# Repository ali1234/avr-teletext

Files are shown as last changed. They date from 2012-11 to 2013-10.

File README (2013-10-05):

avr-teletext
------------

This is a teletext inserter for AVR microcontroller. It adds teletext to an
existing composite signal. It is controlled on I2C and features two modes.
In passthrough mode whole teletext packets are received on I2C and inserted
into the video signal, allowing the broadcast of an interleaved magazine with
multiple pages. In console mode the I2C port receives individual characters
and emulates a framebuffer by generating a single page repeatedly. The console
supports accelerated scrolling.

A video of the device operating is here:
https://plus.google.com/117474986382867317779/posts/eKBn5ePYWbc

Hardware
--------

The hardware schematic is in schematic.png. General parts list:

 * AVR microcontroller. I used Atmega 168. Using a part with more RAM would
   allow for multiple consoles are other fancy stuff.

 * LM1881 sync splitter. For generating horizontal and vertical sync pulses.
   Hard to find in through hole package. I got it at http://www.rapidonline.com

 * 13.875 MHz crystal. For AVR clock. This is double teletext frequency.
   Extremely hard to find. I got it from http://quarndon.co.uk/

 * A diode to hook up the teletext to the video signal.

 * Various resistors and capacitors. Especially you need some filter caps 
   between ground and vcc or the output signal will be too dirty to work.

I2C addresses
-------------

The AVR implements two I2C addresses: data and control.

0x00 - Data address

Bits    Function
0-6     7 bit characters written here will be placed into the output buffer.
7       Unused.

0x01 - Control address

Bits
0       Set mode. 0 = console, 1 = passthrough.
1-7     Unused.

Console mode
------------

In this mode each character received will be written into a character
framebuffer, staring in the top left corner and moving to the right with each 
character. When the end of the line is reached the cursor position moves to the
beginning of the next line. When the bottom of the display is reached the row
pointers into the buffer are shifted by 1 line, and the line at the top of the 
display becomes the line at the bottom. This line is cleared and new characters
go here. Essentially it is a scrolling text console. Newlines are supported.
Setting the cursor position is not supported. The whole buffer is output on a 
loop regardless of whether new data is available.

Passthrough mode
----------------

In this mode each received character is written into the output buffer and then
outputted only once. The buffer is used with a head and tail pointer here. When
a row fills up the head pointer is incremented and when the row is output the 
tail pointer is incremented. If there are no lines to output a filler line is
output instead. This mode is intended to be used to broadcast normal teletext
magazines with multiple interleaved pages.

The Diode
---------
 
The AVR uses SPI to output the teletext signal. The ISR enables TX in the
horizontal interrupt before pushing out the bits at the right moment and 
disables TX afterwards. This is neccessary, because TX would be high when
idle. The original code dealed with it by producing an inverted signal, 
which would later be inverted/coupled with an 74LS244N.

When the teletext generator is idle or goes low, then the circuit should
be disconnected from video, so that the low state does not drain current
from the video signal. This is achieved using a diode. In fact a LED could 
be used which, together with the right resistor value, would produce the 
right voltage level and even indicate data transmission with a flickering 
light. 

During blanking, video has negative levels agains low, but most diodes have
a much larger forwad bias than that difference.

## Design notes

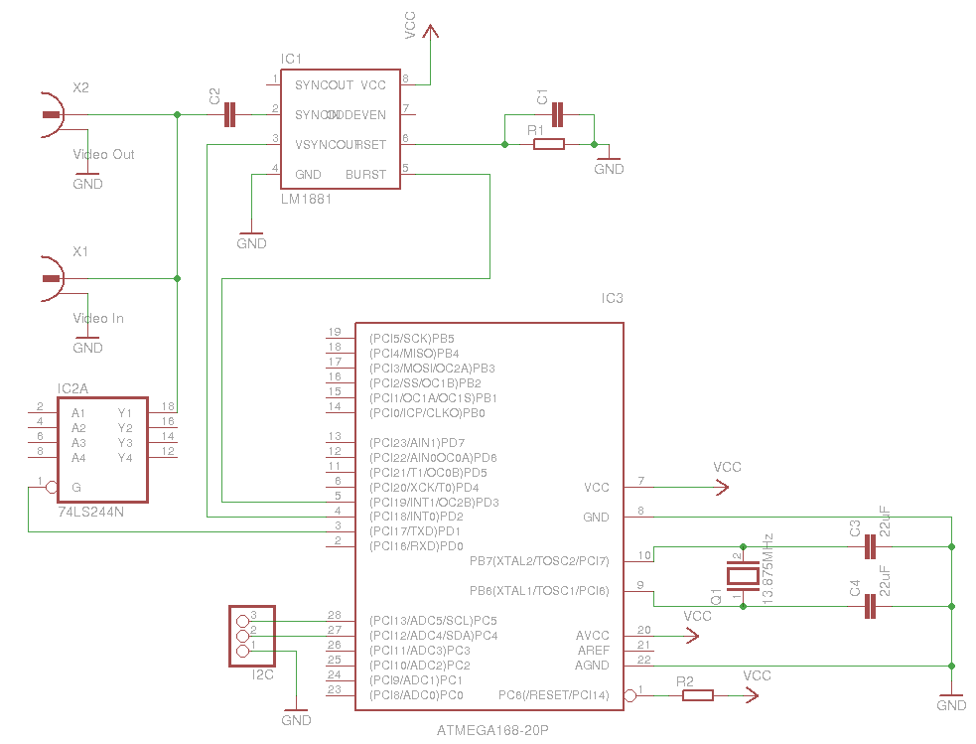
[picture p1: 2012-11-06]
schematic.png

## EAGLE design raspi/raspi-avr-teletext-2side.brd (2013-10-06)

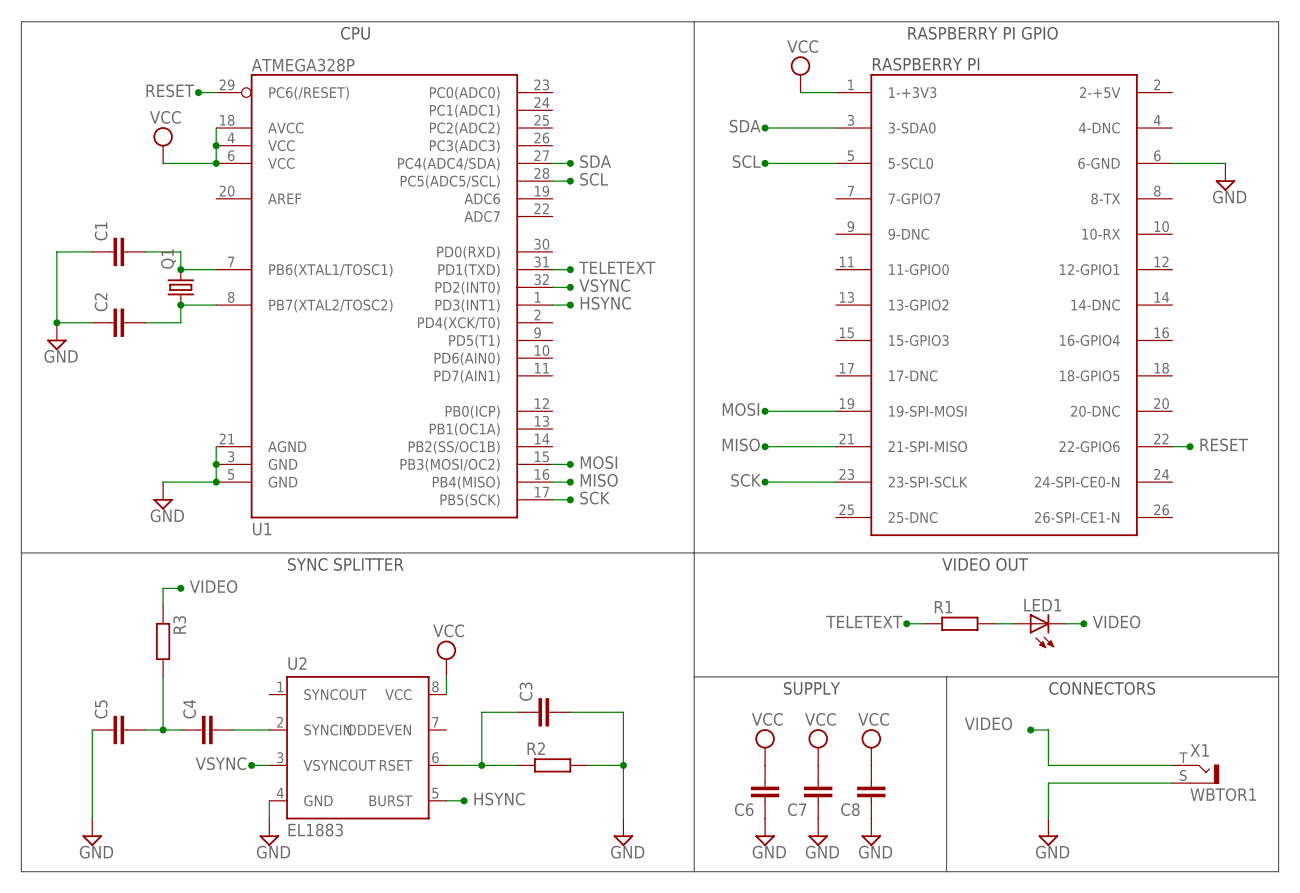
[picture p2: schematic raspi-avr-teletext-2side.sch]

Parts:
C1, C2, C3, C4, C5, C6, C7, C8: C-EUC0603; C0603
D1: RASPBERRY-PI
LED1: LEDCHIP-LED0603; CHIP-LED0603
Q1: CRYSTALHC49U-V; HC49U-V
R1, R2, R3: R-EU_R0603; R0603
U1: ATMEGA328P; TQFP32-08
U2: EL1883; SOIC8
X1: WBTOR1

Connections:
GND: C1.1, C2.1, C3.2, C5.1, C6.1, C7.1, C8.1, D1.6 (6-GND), R2.2, U1.3 (GND), U1.5 (GND), U1.21 (AGND), U2.4 (GND), X1.S
HSYNC: U1.1 (PD3(INT1)), U2.5 (BURST)
MISO: D1.21 (21-SPI-MISO), U1.16 (PB4(MISO))
MOSI: D1.19 (19-SPI-MOSI), U1.15 (PB3(MOSI/OC2))
unnamed: C1.2, Q1.2, U1.7 (PB6(XTAL1/TOSC1))
unnamed: C2.2, Q1.1, U1.8 (PB7(XTAL2/TOSC2))
unnamed: C3.1, R2.1, U2.6 (RSET)
unnamed: LED1.A, R1.2
unnamed: C4.2, U2.2 (SYNCIN)
unnamed: C4.1, C5.2, R3.2
RESET: D1.22 (22-GPIO6), U1.29 (PC6(/RESET))
SCK: D1.23 (23-SPI-SCLK), U1.17 (PB5(SCK))
SCL: D1.5 (5-SCL0), U1.28 (PC5(ADC5/SCL))
SDA: D1.3 (3-SDA0), U1.27 (PC4(ADC4/SDA))
TELETEXT: R1.1, U1.31 (PD1(TXD))
VCC: C6.2, C7.2, C8.2, D1.1 (1-+3V3), U1.4 (VCC), U1.6 (VCC), U1.18 (AVCC), U2.8 (VCC)
VIDEO: LED1.C, R3.1, X1.T
VSYNC: U1.32 (PD2(INT0)), U2.3 (VSYNCOUT)

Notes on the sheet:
RASPBERRY PI
SYNC SPLITTER
CPU
RASPBERRY PI GPIO
VIDEO OUT
SUPPLY
CONNECTORS

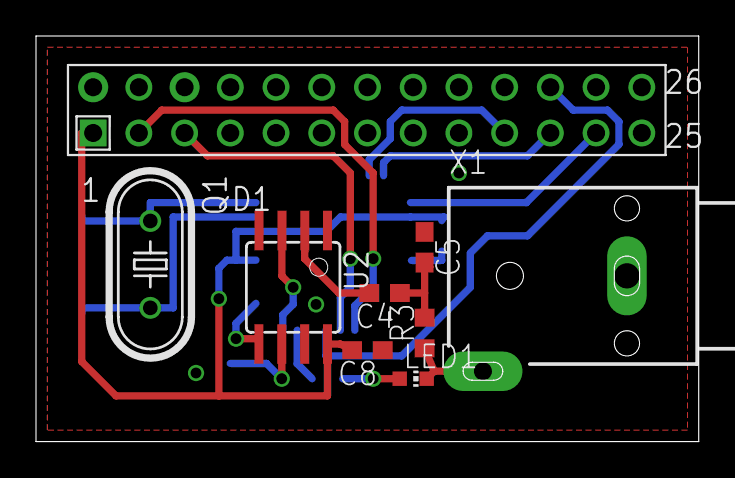
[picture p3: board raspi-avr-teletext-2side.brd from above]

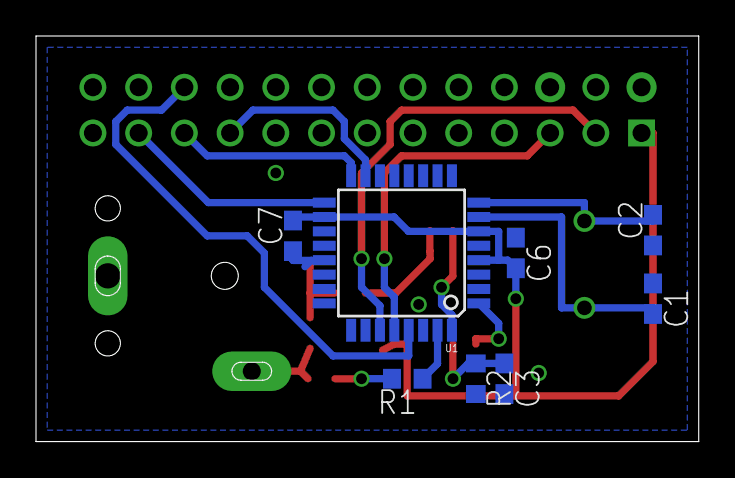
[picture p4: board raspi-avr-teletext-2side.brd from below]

Board: 2 copper layers, 36.8 x 22.5 mm, 17 parts (8 on the bottom side), 18 nets.

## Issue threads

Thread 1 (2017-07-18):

Where do the files go

nat2001, 2017-07-18:
This may be a very silly question, but which of these files go on the AVR and which on the Pi itself? I'd like to try this.

ali1234, 2017-07-18:
If you are using a raspberry pi then you probably want raspi-teletext
instead. avr-teletext is not related and does not provide anything except
an avr firmware that you have to program yourself.

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

nat2001, 2017-07-19:
I'm thinking about making a 'proper' teletext inserter. If this is the AVR Firmware, do you use somthing like vbit2 to send the page data to the avr, or is there some other way that is over my head?

ali1234, 2017-07-23:
You have to send the data to the AVR over i2c, because the serial port is used to generate the signal to the TV. So you need to use some other device with i2c master to write the raw teletext bytes into register 0x00. I don't think the code to do this was ever released but it would be only a few lines of python to make it work on something like a raspberry pi. You would need a voltage shifter though. Also this isn't a 'proper' inserter by any means, it is a hack and will generate ugly signals, so don't even think about using it for anything serious. Buy a vbit (hardware) from Peter if you want that. I wrote this AVR stuff to see how cheap I could make an inserter, but when I discovered the Pi can do it with no extra hardware at all I stopped working on this.

nat2001, 2017-07-23:
OK. I wasn't planning on doing anything 'serious' with it, but I think I should try something else, or forget it and just be content with what I've got.

Closed 2017-07-30.

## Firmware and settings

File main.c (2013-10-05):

/* 
    Copyright 2012 Alistair Buxton <a.j.buxton@gmail.com>

    This file is part of avr-teletext.

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
    You should have received a copy of the GNU General Public License
    along with avr-teletext.  If not, see <http://www.gnu.org/licenses/>.
*/

#include <inttypes.h>
#include <avr/io.h>
#include <avr/wdt.h>
#include <avr/interrupt.h>
#include <avr/pgmspace.h>

#include "globals.h"
#include "console.h"
#include "utils.h"

#define WITH_LM1881

#define nop() __asm__ __volatile__("nop\nnop\nnop\nnop");

void io_setup(void)
{

// +---+-----+-----+-----+-----+-----+-----+-----+-----+
// |   |  0  |  1  |  2  |  3  |  4  |  5  |  6  |  7  |
// +---+-----+-----+-----+-----+-----+-----+-----+-----+
// | B | OUT | OUT | OUT | OUT | IN  | IN  |  Crystal  |
// +---+-----+-----+-----+-----+-----+-----+-----+-----+
// | C | OUT | OUT | OUT | OUT | SDA | SCL | RST |  -  |
// +---+-----+-----+-----+-----+-----+-----+-----+-----+
// | D | RXD | TXD |INT0 |INT1 | T0  | T1  | OUT | OUT |
// +---+-----+-----+-----+-----+-----+-----+-----+-----+

    // D[7] = shifter enable
    DDRD = 0x12; PORTD = 0;

    // SPI setup
    // baud Fosc/2
    UBRR0H = 0;
    UBRR0L = 0;
    // USART0 MSPIM mode, LSB
    UCSR0C = 0xc4;
    // We don't enable TX yet, because it will go high when idle
    // TX is enabled in the ISR during sending.
    UCSR0B = 0;

    // TWI setup
    // no need to set baud rate for slave mode
    // enable pull-ups
    DDRC = 0x00; PORTC = 0x30;
    // match addresses 0x40 - 0x7f
    TWAR = 0x40<<1;
    TWAMR = 0x1f<<1;
    // enable TWI, no interrupt request
    TWCR = _BV(TWEN) | _BV(TWEA);

    // external INT0 and INT1 enable
    EICRA = 0x0b;
    EIMSK = 0x03;

    sei();

}

volatile uint8_t line_counter;
volatile uint8_t tt_buffer[NBUFFERS][42];
volatile uint8_t buffer_head = 0;
volatile uint8_t buffer_tail = 0;

/* Buffer that we send when we have nothing else to do. */
const uint8_t fill_buffer[42] PROGMEM = {
    0x49, 0x15, 0x15, 0x15, 0x15, 0x15, 0x15, 0x15,
    0x15, 0x15, 
    0x20, 0x20, 0x20, 0x20, 0x20, 0x20, 0x20, 0x20, 
    0x20, 0x31, 0xb0, 0xb0, 0x20, 0x54, 0x75, 0xe5, 
    0x20, 0x31, 0x37, 0x20, 0x4a, 0x61, 0x6e, 0x83, 
    0x32, 0x31, 0xba, 0xb5, 0xb0, 0x2f, 0xb3, 0xb6
};

/* hmm */

#define BLACK "\x80"
#define RED "\x01"
#define GREEN "\x02"
#define YELLOW "\x83"
#define BLUE "\x04"
#define MAGENTA "\x85"
#define CYAN "\x86"
#define WHITE "\x07"

#define FLASHON "\x08"
#define FLASHOFF "\x09"
#define ENDBOX "\x0A"
#define STARTBOX "\x0B"
#define NORMAL "\x0C"
#define DOUBLEH "\x0D"
#define DOUBLEW "\x0E"
#define DOUBLEWH "\x0F"

/*
 0123456789012345678901234567890123456789
*/
const char long_text[] PROGMEM = 
"       "DOUBLEWH"H e l l o   w o r l d !\n"
"\n"
"\n"
"           "RED"* "GREEN"* "YELLOW"* "BLUE"* "MAGENTA"* "CYAN"*\n\n"
"  The"CYAN"AVR"WHITE"is a modified Harvard\n"
"architecture 8-bit RISC single chip\n"
"microcontroller which was developed by\n"
"Atmel in"GREEN"1996."WHITE"The AVR was one of the\n"
"first microcontroller families to use\n"
"on-chip flash memory for program\n"
"storage, as opposed to one-time\n"
"programmable ROM, EPROM, or EEPROM used\n"
"by other microcontrollers at the time.\n"
"\n"
"           "RED"* "GREEN"* "YELLOW"* "BLUE"* "MAGENTA"* "CYAN"*\n\n"
" "YELLOW"Teletext"WHITE"(or \"broadcast teletext\") is\n"
"a television information retrieval\n"
"service developed in the United Kingdom\n"
"in the early"GREEN"1970s."WHITE"It offers a range\n"
"of text-based information, typically\n"
"including national, international and\n"
"sporting news, weather and television\n"
"schedules. Subtitle information is also\n"
"transmitted in the teletext signal,\n"
"typically on page 888, 777 or 333."
;

extern uint8_t first_row;

void run_demo(void) {

    for(;;)
    {
        int text_pos;
        char c;
        text_pos = 0;
        //console_clear();
        while((c = pgm_read_byte(&(long_text[text_pos]))) != 0) {
            console_putchar(c);
            delay_ms(10);
            text_pos++;
        }
        //delay_s(1);
        console_putchar('\n');
        console_putchar('\n');
    }

}

int main(void)
{
    uint8_t dest_register = 0xff;
    uint8_t control = 0;
    uint8_t twdr = 0;
    uint8_t twsr = 0;

    io_setup();
    console_setup();
    control=0;
    //run_demo();

    for(;;)
    {
        
        if(TWCR&0x80) {
            twdr = TWDR;
            twsr = TWSR;
            TWCR |= 0x80;

            switch(twsr&0xf8) {
                case 0x60:
                case 0x68:
                    dest_register = (twdr>>1)&(TWAMR>>1);
                    if(control&0x01) passthrough_start();
                    break;
                case 0x80:
                    switch(dest_register) {
                        case 0:
                            if(control&0x01) passthrough_putchar(twdr);
                            else console_putchar(twdr&0x7f);
                            break;
                        case 1:
                            control = twdr;
                            if(control&0x01) passthrough_setup();
                            else console_setup();
                            break;
                        default:
                            
                            break;
                    }
                    break;
                default:
                    dest_register = 0xff;
                    //error - bail out
                    break;
            }
            // clear interrupt
        }
        //delay_ms(1);
    }
    
    // Never reached.
    return(0);
}

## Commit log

2012-02-05 Use proper register names. Move around some things to make sure uart doesn't underflow.
2012-11-06 Fixup some i2c stuff.
    [main.c]
2012-11-06 Add schematic.
2012-11-06 Fix the year on copyright message.
    [main.c]
2013-10-05 Replace buffer/inverter with a diode.
    Turn off the Tx hardware so it doesn't pull the line high
    when there is no data. Don't invert the data before writing
    it out.
    [main.c]
2013-10-05 Allow device selection in Makefile
    Conflicts:
    Makefile
2013-10-05 ISR has to restore r1 to whatever it's previous value was, not 0.
    r1 equals 0 by convention, but interrupt may happen in the middle
    of a function before the value is restored.
2013-10-05 Schematics for Raspberry Pi extension board.
    [raspi-avr-teletext-2side.brd, raspi-avr-teletext-2side.sch]
2013-10-06 Fix MOSI/MISO
    I can never remember whether you are supposed to flip these or not.
    [raspi-avr-teletext-2side.brd, raspi-avr-teletext-2side.sch]

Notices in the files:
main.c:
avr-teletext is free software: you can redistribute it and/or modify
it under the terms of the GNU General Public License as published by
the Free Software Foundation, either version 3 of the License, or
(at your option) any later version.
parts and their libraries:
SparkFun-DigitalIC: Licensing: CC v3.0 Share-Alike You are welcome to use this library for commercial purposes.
